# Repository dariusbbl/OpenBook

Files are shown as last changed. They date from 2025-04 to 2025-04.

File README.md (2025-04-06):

# OpenBook

# Block Diagram
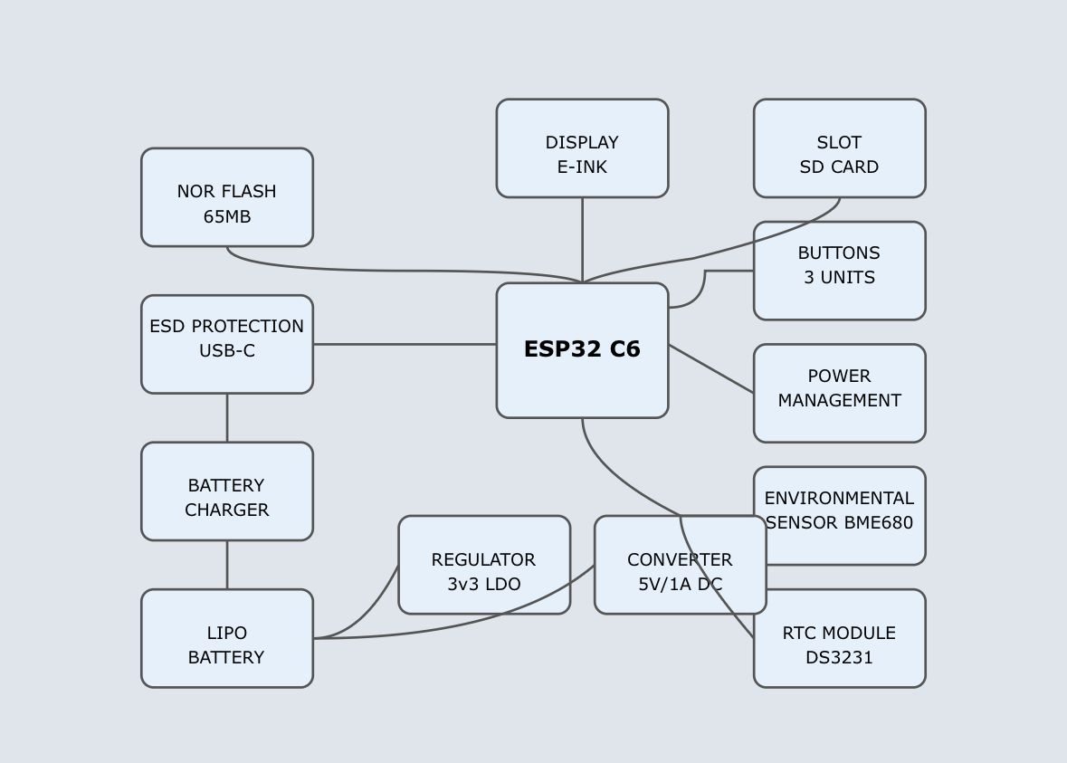
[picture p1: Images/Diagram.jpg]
Diagrama


# Hardware Components
#### Microcontroller – ESP32-C6
- **Core Architecture:** 32-bit RISC-V processor  
- **Wireless Support:** Integrated Wi-Fi 6 and Bluetooth Low Energy 5.0  
- **I/O Capabilities:** Supports multiple digital interfaces – SPI, I²C, UART, PWM, and general-purpose IO  
- **Power Features:** Low-energy design with deep sleep functionality for battery-powered applications

#### Real-Time Clock – DS3231SN
- **Accuracy:** ±2 ppm  
- **Communication:** I²C (`SDA`, `SCL`)  
- **Backup Power:** Supercapacitor-based retention

#### E-Paper Display
- **Connection Method:** 20-pin dedicated header  
- **Communication Protocol:** SPI + GPIO  
- **Key Signals:** `EPD_CS`, `EPD_DC`, `EPD_RST`, `EPD_BUSY`, etc.  
- **Advantages:** Zero power draw when idle, high readability in sunlight

#### MicroSD Card Slot
- **Interface:** SPI (connected to IO4 through IO9)  
- **Purpose:** Storing eBooks, setting and user configuration data  

#### Environmental Sensor – BME688
- **Measurements:** Temperature, Humidity, Pressure and VOCs  
- **Interface:** I²C  
- **Pins:** `SDA` – IO1, `SCL` – IO2  
- **Power Supply:** 3.3V  
- **Default Address:** `0x76` 

#### Environmental Sensor – BME688 Battery Fuel Gauge - MAX17048
- **Role:** Estimates remaining charge in LiPo(Lithium Polymer) battery
- **Protocol:** I²C (shared on IO1, IO2)  

#### Environmental Sensor – BME688 I²C Expansion – Qwiic / Stemma QT
- **Connector:** 4-pin (3V3, GND, SDA, SCL)  
- **Protocol:** I²C (`IO1`, `IO2`)  
- **Compatibility:** Plug-and-play with Adafruit / SparkFun modules  

#### Environmental Sensor – BME688 Voltage Supervisor – BD52xx
- **Purpose:** Monitors voltage levels, triggers safe reset  
- **Control Pin:** IO0

#### MCP73831 – Charging Controller
- **Function:** LiPo charging via USB (3.7V)  
- **Charging Current:** ~500 mA  
- **Indicator:** Status LED  

# BOM (Bill Of Materials)

| Componenta | Link | Datasheet |
|---|---|---|
| BUTTON | [Model](https://industry.panasonic.com/global/en/products/control/switch/light-touch/number/evqpuj02k) | [Datasheet](https://www.lcsc.com/datasheet/lcsc_datasheet_2201121800_PANASONIC-EVQPUJ02K_C2936858.pdf) |
| CAPACITOR | [Model](https://componentsearchengine.com/part-view/R0402%201%25%20100%20K%20(RC0402FR-07100KL)/YAGEO) | [Datasheet](//efaidnbmnnnibpcajpcglclefindmkaj/https://www.resistor.com/assets/pdf/0402tstd.pdf) |
| CPH3225A | [Model](https://www.snapeda.com/parts/CPH3225A/Seiko+Instruments/view-part/?ref=eda) | [Datasheet](https://octopart.com/datasheet/cph3225a-seiko-25340571) |
| EVQPUJ02K | [Model](https://industry.panasonic.com/global/en/products/control/switch/light-touch/number/evqpuj02k) | [Datasheet](https://www.lcsc.com/datasheet/lcsc_datasheet_2201121800_PANASONIC-EVQPUJ02K_C2936858.pdf) |
| KP-1608SURCK | [Model](https://www.snapeda.com/parts/KP-1608SURCK/Kingbright/view-part/?ref=search&t=LED%200603) | [Datasheet](//efaidnbmnnnibpcajpcglclefindmkaj/https://media.elv.com/file/107153_led_surck1608_data.pdf) |
| USBLC6-2SC6Y | [Model](https://www.snapeda.com/parts/USBLC6-2SC6Y/STMicroelectronics/view-part/?ref=eda) | [Datasheet](https://www.digikey.com/en/htmldatasheets/production/1375342/0/0/1/usblc6-2sc6y) |
| SD0805S020S1R0 | [Model](https://ro.mouser.com/ProductDetail/KYOCERA-AVX/SD0805S020S1R0?qs=jCA%252BPfw4LHbpkAoSnwrdjw%3D%3D) | [Datasheet](https://www.alldatasheet.com/view.jsp?Searchword=SD0805S&sField=2) |
| PGB1010603MR | [Model](https://www.snapeda.com/parts/PGB1010603MR/Littelfuse/view-part/?ref=eda) | [Datasheet](https://www.alldatasheet.com/view.jsp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) |
| BD5229G-TR  | [Model](https://componentsearchengine.com/part-view/BD5229G-TR/ROHM%20Semiconductor) | [Datasheet](https://www.lcsc.com/datasheet/lcsc_datasheet_2201131330_ROHM-Semicon-BD5229G-TR_C962636.pdf) |
| XC6220A331MR-G | [Model](https://componentsearchengine.com/part-view/XC6220A331MR-G/Torex) | [Datasheet](https://www.alldatasheet.com/view.jsp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) |
| XC6220A331MR-G | [Model](https://componentsearchengine.com/part-view/XC6220A331MR-G/Torex) | [Datasheet](https://www.alldatasheet.com/view.jsp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) |
| USB4110-GF-A  | [Model](https://componentsearchengine.com/part-view/USB4110-GF-A/GCT%20(GLOBAL%20CONNECTOR%20TECHNOLOGY)) | [Datasheet](//efaidnbmnnnibpcajpcglclefindmkaj/https://gct.co/files/drawings/usb4110.pdf) |
| Adafruit | [Model](https://eu.mouser.com/ProductDetail/Adafruit/4208?qs=PzGy0jfpSMtbScLbr0L5dw%3D%3D) | [Datasheet](https://www.arrow.com/en/manufacturers/adafruit-industries/datasheets) |
| Bobina | [Model](https://store.comet.srl.ro/Catalogue/Product/43497/) | [Datasheet](https://www.scribd.com/document/814581278/Datasheet-Bobina) |
| PFMF | [Model](https://www.mouser.co.uk/ProductDetail/EPCOS-TDK/B72520T0350K062?qs=dEfas%2FXlABIszF52uu7vrg%3D%3D) | [Datasheet](https://ro.mouser.com/c/ds/circuit-protection/thermistors/resettable-fuses-pptc/?m=Schurter&series=PFMF) |
| DMG2305UX-7 | [Model](https://componentsearchengine.com/part-view/DMG2305UX-7/Diodes%20Incorporated) | [Datasheet](//efaidnbmnnnibpcajpcglclefindmkaj/https://www.mouser.com/datasheet/2/115/DMG2305UX-266242.pdf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) |
| Si1308EDL-T1-GE3 | [Model](https://componentsearchengine.com/part-view/SI1308EDL-T1-GE3/Vishay) | [Datasheet](https://www.alldatasheet.com/view.jsp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) |
| R0402 | [Model](https://componentsearchengine.com/part-view/R0402%201%25%20100%20K%20(RC0402FR-07100KL)/YAGEO) | [Datasheet](//efaidnbmnnnibpcajpcglclefindmkaj/https://www.resistor.com/assets/pdf/0402tstd.pdf) |
| BME680 | [Model](https://www.snapeda.com/parts/BME680/Bosch/view-part/?welcome=home) | [Datasheet](//efaidnbmnnnibpcajpcglclefindmkaj/https://www.bosch-sensortec.com/media/boschsensortec/downloads/datasheets/bst-bme680-ds001.pdf) |
| SMD Solder | [Model](https://grabcad.com/library/solder-jumpers-1) | [Datasheet]() |
| W25Q512JVEIQ | [Model](https://www.snapeda.com/parts/ESP32-C6-WROOM-1-N8/Espressif+Systems/view-part/?ref=eda) | [Datasheet](//efaidnbmnnnibpcajpcglclefindmkaj/https://www.mouser.com/datasheet/2/949/W25Q512JV_SPI_RevB_06252019_KMS-2487502.pdf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) |
| ESP32-C6-WROOM-1-N8 | [Model](https://www.snapeda.com/parts/ESP32-C6-WROOM-1-N8/Espressif+Systems/view-part/?ref=eda) | [Datasheet](//efaidnbmnnnibpcajpcglclefindmkaj/https://www.mouser.com/catalog/specsheets/Espressif_ESP32_C6_WROOM_1%20_Datasheet_V0.1_PRELIMINARY_en.pdf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) |
| DS3231SN# | [Model](https://www.snapeda.com/parts/DS3231SN%23/Analog+Devices/view-part/?ref=eda) | [Datasheet](https://www.alldatasheet.com/view.jsp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) |
| MAX17048G+T10 | [Model](https://www.snapeda.com/parts/MAX17048G+T10/Analog+Devices/view-part/?ref=eda) | [Datasheet](https://www.alldatasheet.com/view.jsp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) |
| MCP73831T-5ACI/OT | [Model](https://www.mouser.co.uk/ProductDetail/Microchip-Technology/MCP73831T-5ACI-OT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) | [Datasheet](//efaidnbmnnnibpcajpcglclefindmkaj/https://ww1.microchip.com/downloads/en/DeviceDoc/MCP73831-Family-Data-Sheet-DS20001984H.pdf) |

### ESP32-C6 Hardware Connections Overview  

| **Peripheral** | **Connected Pin(s)** | **Protocol** | **Functionality Description** |
|---|---|---|---|
| **E-Paper Display** | IO7 (MOSI), IO6 (SCK), IO10 (CS), IO5 (DC), IO23 (RST), IO3 (BUSY) | SPI | Sends visual data and manages display operations. |
| **MicroSD Card Module** | IO7 (MOSI), IO6 (SCK), IO4 (SS_SD), IO2 (MISO) | SPI | Enables saving and reading of e-book files. |
| **BME688 Environmental Sensor** | IO21 (SDA), IO22 (SCL) | I2C | Measures environmental factors like temperature, humidity, pressure, and gas levels. |
| **DS3231 RTC Module** | IO21 (SDA), IO22 (SCL), IO18 (RST), IO1 (32KHz), IO0 (INT_RTC) | I2C | Maintains accurate timekeeping even when the main system is off. |
| **External NOR Flash** | IO11 (CS), IO6 (SCK), IO2 (MISO), IO7 (MOSI) | SPI | Offers extra non-volatile memory for storing application-specific data. |
| **Battery Status Monitor**  | IO21 (SDA), IO22 (SCL) | I2C | Monitors power level and battery condition. |
| **USB-C Interface** | GPIOs via regulated voltage lines | USB | Supplies power and facilitates programming access. |
| **User Input Buttons** | IO9 (BOOT), IO15 (CHANGE), EN (RESET) | GPIO | Detects user interaction through physical button presses. |

# Decision & Modifications
- To address the design checker errors, I adjusted the dimensions of several components.
- The main components were positioned exactly according to the provided specifications to ensure a perfect match between the PCB dimensions and the case. Component placement was carefully planned to allow for efficient routing. The battery was placed in the remaining free space within the case.
- A ground plane was created on both the top and bottom layers to improve signal integrity and reduce noise.
- Routing was performed on both the top and bottom layers. Power traces were placed exclusively on the top layer to avoid the use of vias.
- Diodes (SMD-Hole): The initial footprint included through-hole pads that were too narrow, potentially leading to soldering difficulties and poor connectivity. To address this, the pad dimensions were modified to 35 mil × 190 mil, improving both manufacturability and the reliability of the electrical contact.
- U4 – MAX17048G+T10: The VBAT power trace was routed with a width of 0.3 mm due to design constraints. However, the original footprint featured pin widths of just 0.27 mm, which caused mismatches and disrupted routing symmetry. The pad widths were therefore increased to match the trace width, ensuring consistent routing and improved layout balance.

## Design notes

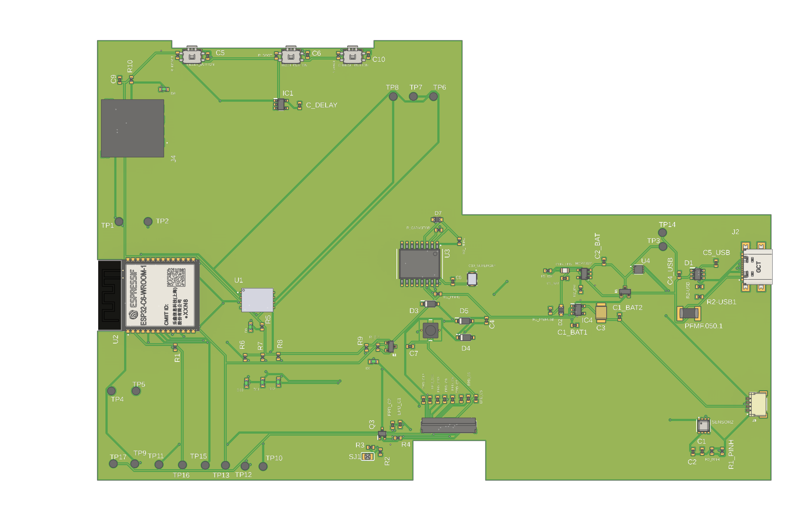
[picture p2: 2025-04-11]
Images/3D_updated.png

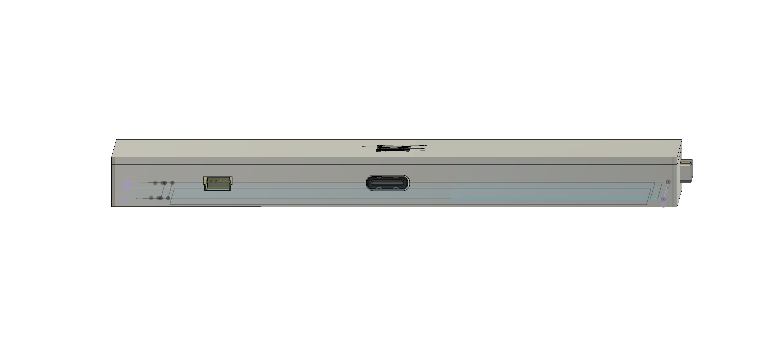
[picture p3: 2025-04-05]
Images/Ports.png

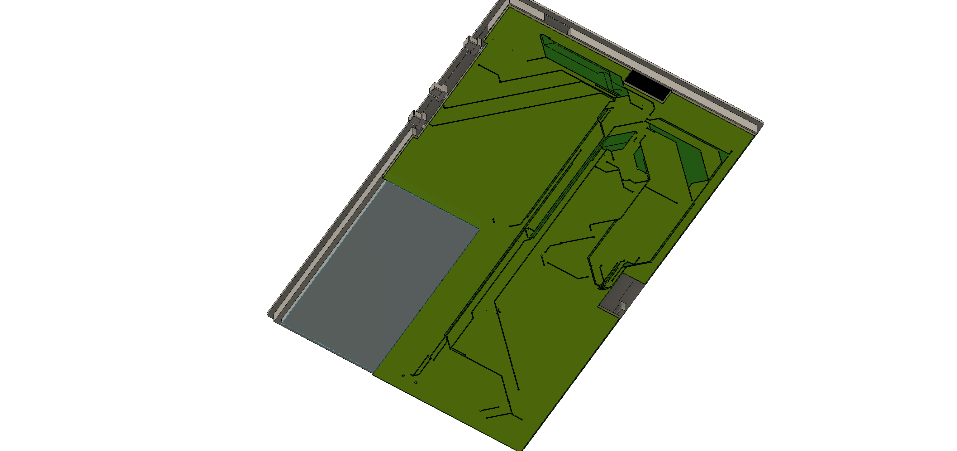
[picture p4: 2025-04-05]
Images/BoardBack.png

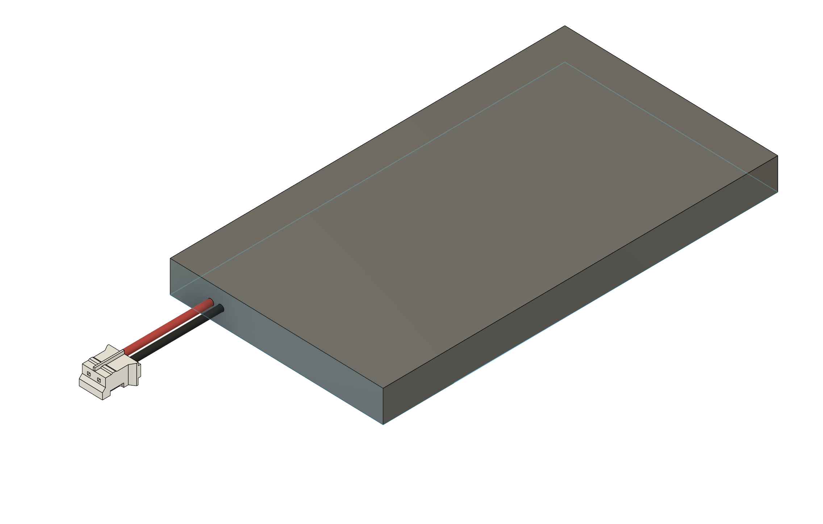
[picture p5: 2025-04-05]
Images/Battery.png

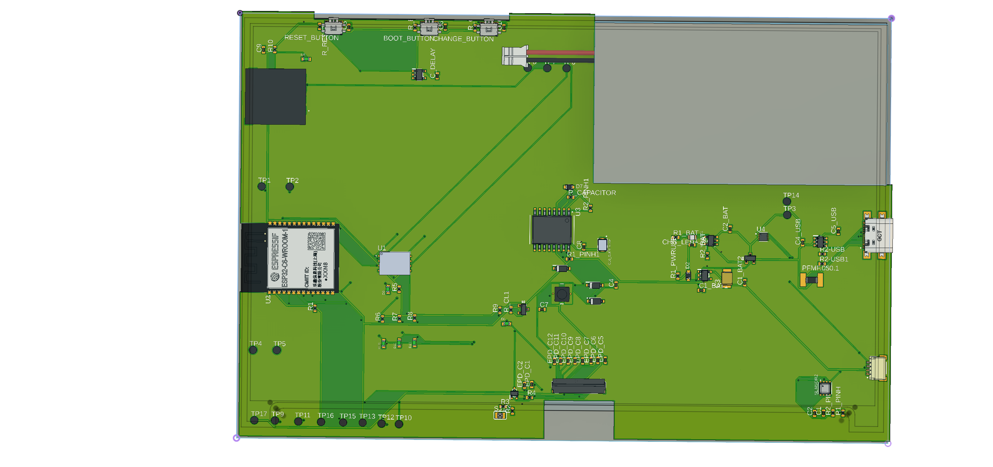
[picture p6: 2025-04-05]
Images/Board.png

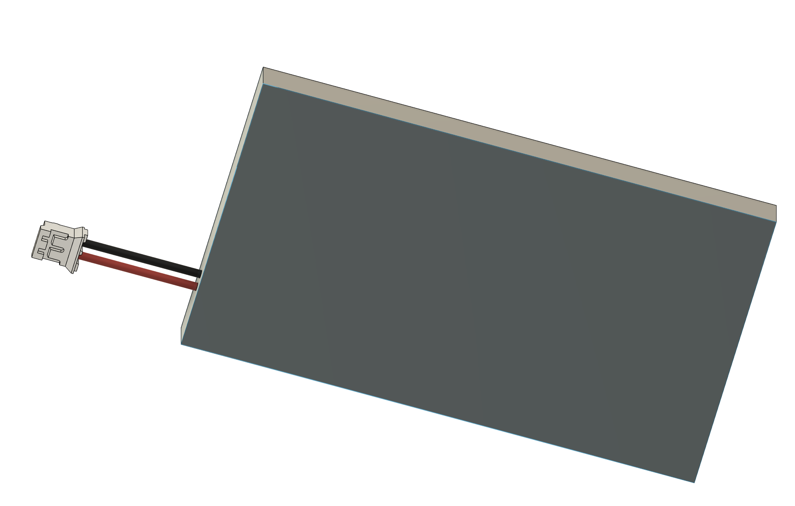
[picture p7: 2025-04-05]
Images/BatteryBack.png

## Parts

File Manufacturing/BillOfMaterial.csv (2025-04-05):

Qty | Value | Device | Package | Parts | Description | ARROW_PART_NUMBER | ARROW_PRICE-STOCK | AVAILABILITY | CENTROID_NOT_SPECIFIED | CHECK_PRICES | COPYRIGHT | DATASHEET | DESCRIPTION | DIGIKEY_DESCRIPTION | DIGIKEY_PART_NUMBER | HEIGHT | LEAD_FREE | MANUFACTURER_NAME | MANUFACTURER_PART_NUMBER | MF | MFR_NAME | MOUSER_PART_NUMBER | MOUSER_PRICE-STOCK | MOUSER_TESTING_PART_NUMBER | MOUSER_TESTING_PRICE-STOCK | MP | MPN | PACKAGE | POPULARITY | PREFIX | PRICE | PROD_ID | PURCHASE-URL | ROHS | SNAPEDA_LINK | SPICEMODEL | SPICEPREFIX | TEMPERATURE_RANGE_HIGH | TEMPERATURE_RANGE_LOW | TP_SIGNAL_NAME | VALUE
1 |  | ADAFRUIT_LEDCHIP-LED0603 | ADAFRUIT_CHIP-LED0603 | CHG_LED | LED
1 |  | SJ | SJ | SJ1 | SMD solder JUMPER |  |  |  |  |  |  |  |  |  |  |  |  |  |  |  |  |  |  |  |  |  |  |  | 3
1 | 0.1uF/50V | ESP32_WROVER_EAGLE-LTSPICE_CC0402 | ESP32_WROVER_EAGLE-LTSPICE_C0402 | EPD_C5 | CAPACITOR, European symbol |  |  |  |  |  |  |  |  |  |  |  |  |  |  |  |  |  |  |  |  |  |  |  |  |  |  |  |  |  |  | NONE | C
1 | 0.47 | ESP32_WROVER_EAGLE-LTSPICE_RR0402 | ESP32_WROVER_EAGLE-LTSPICE_R0402 | R3 | RESISTOR, European symbol |  |  |  |  |  |  |  |  |  |  |  |  |  |  |  |  |  |  |  |  |  |  |  |  |  |  |  |  |  |  | NONE | R
1 | 100K | ESP32_WROVER_EAGLE-LTSPICE_RR0402 | ESP32_WROVER_EAGLE-LTSPICE_R0402 | R1_PWRUSB | RESISTOR, European symbol |  |  |  |  |  |  |  |  |  |  |  |  |  |  |  |  |  |  |  |  |  |  |  |  |  |  |  |  |  |  | NONE | R
8 | 100nF | ESP32_WROVER_EAGLE-LTSPICE_CC0402 | ESP32_WROVER_EAGLE-LTSPICE_C0402 | C1, C2, C4_USB, C6, C8, C9, C10, C_DELAY | CAPACITOR, European symbol |  |  |  |  |  |  |  |  |  |  |  |  |  |  |  |  |  |  |  |  |  |  |  |  |  |  |  |  |  |  | NONE | C
1 | 100uF TANT | RCL_CPOL-EUCT3528 | RCL_CT3528 | C3 | POLARIZED CAPACITOR, European symbol |  |  |  |  |  |  |  |  |  |  |  |  |  |  |  |  |  |  |  |  |  |  |  | 0 |  |  |  |  |  |  |  | C
15 | 10K | ESP32_WROVER_EAGLE-LTSPICE_RR0402 | ESP32_WROVER_EAGLE-LTSPICE_R0402 | R1, R1_PINH, R1_PINH1, R2_PINH, R2_PINH1, R4, R5, R6, R7, R9, R10, R_BOOT, R_CHANGE, R_CL1, R_RESET | RESISTOR, European symbol |  |  |  |  |  |  |  |  |  |  |  |  |  |  |  |  |  |  |  |  |  |  |  |  |  |  |  |  |  |  | NONE | R
1 | 10k | ESP32_WROVER_EAGLE-LTSPICE_RR0402 | ESP32_WROVER_EAGLE-LTSPICE_R0402 | R8 | RESISTOR, European symbol |  |  |  |  |  |  |  |  |  |  |  |  |  |  |  |  |  |  |  |  |  |  |  |  |  |  |  |  |  |  | NONE | R
1 | 10uF | ESP32_WROVER_EAGLE-LTSPICE_CC0402 | ESP32_WROVER_EAGLE-LTSPICE_C0402 | C7 | CAPACITOR, European symbol |  |  |  |  |  |  |  |  |  |  |  |  |  |  |  |  |  |  |  |  |  |  |  |  |  |  |  |  |  |  | NONE | C
1 | 112A-TAAR-R03_ATTEND | 112A-TAAR-R03_ATTEND | 112ATAARR03ATTEND | J4 | Micro SD Card Socket, Push-Push Type, Top Mount, SMT, H=1.83mm, 10u |  |  |  |  |  |  |  | Micro SD Card Socket | Push-Push Type | Top Mount | SMT | H=1.83mm | 10u |  |  | 1.9mm |  | ATTEND | 112A-TAAR-R03 ATTEND
1 | 15 | ESP32_WROVER_EAGLE-LTSPICE_RR0402 | ESP32_WROVER_EAGLE-LTSPICE_R0402 | R_CAPACITOR | RESISTOR, European symbol |  |  |  |  |  |  |  |  |  |  |  |  |  |  |  |  |  |  |  |  |  |  |  |  |  |  |  |  |  |  | NONE | R
1 | 1uF | ESP32_WROVER_EAGLE-LTSPICE_CC0402 | ESP32_WROVER_EAGLE-LTSPICE_C0402 | C5 | CAPACITOR, European symbol |  |  |  |  |  |  |  |  |  |  |  |  |  |  |  |  |  |  |  |  |  |  |  |  |  |  |  |  |  |  | NONE | C
9 | 1uF/50V | ESP32_WROVER_EAGLE-LTSPICE_CC0402 | ESP32_WROVER_EAGLE-LTSPICE_C0402 | EPD_C1, EPD_C2, EPD_C6, EPD_C7, EPD_C8, EPD_C9, EPD_C10, EPD_C11, EPD_C12 | CAPACITOR, European symbol |  |  |  |  |  |  |  |  |  |  |  |  |  |  |  |  |  |  |  |  |  |  |  |  |  |  |  |  |  |  | NONE | C
1 | 2.2 | ESP32_WROVER_EAGLE-LTSPICE_RR0402 | ESP32_WROVER_EAGLE-LTSPICE_R0402 | R2 | RESISTOR, European symbol |  |  |  |  |  |  |  |  |  |  |  |  |  |  |  |  |  |  |  |  |  |  |  |  |  |  |  |  |  |  | NONE | R
1 | 200 | ESP32_WROVER_EAGLE-LTSPICE_RR0402 | ESP32_WROVER_EAGLE-LTSPICE_R0402 | R1_BAT | RESISTOR, European symbol |  |  |  |  |  |  |  |  |  |  |  |  |  |  |  |  |  |  |  |  |  |  |  |  |  |  |  |  |  |  | NONE | R
2 | 20V/4.2A/52mO/1.4W | ESP32_WROVER_SPARKFUN-DISCRETESEMI_MOSFET_PCH-DMG2305UX-7 | ESP32_WROVER_SPARKFUN-DISCRETESEMI_SOT23-3 | Q1, Q2 | P-channel MOSFETs |  |  |  |  |  |  |  |  |  |  |  |  |  |  |  |  |  |  |  |  |  |  |  |  |  |  | TRAN-14388 |  |  |  |  |  |  |  |  | 20V/4.2A/52mO/1.4W
1 | 2K | ESP32_WROVER_EAGLE-LTSPICE_RR0402 | ESP32_WROVER_EAGLE-LTSPICE_R0402 | R2_BAT | RESISTOR, European symbol |  |  |  |  |  |  |  |  |  |  |  |  |  |  |  |  |  |  |  |  |  |  |  |  |  |  |  |  |  |  | NONE | R
5 | 4.7uF | ESP32_WROVER_EAGLE-LTSPICE_CC0402 | ESP32_WROVER_EAGLE-LTSPICE_C0402 | C1_BAT, C1_BAT1, C1_BAT2, C2_BAT, C5_USB | CAPACITOR, European symbol |  |  |  |  |  |  |  |  |  |  |  |  |  |  |  |  |  |  |  |  |  |  |  |  |  |  |  |  |  |  | NONE | C
1 | 4.7uF/25V | ESP32_WROVER_EAGLE-LTSPICE_CC0402 | ESP32_WROVER_EAGLE-LTSPICE_C0402 | C4 | CAPACITOR, European symbol |  |  |  |  |  |  |  |  |  |  |  |  |  |  |  |  |  |  |  |  |  |  |  |  |  |  |  |  |  |  | NONE | C
2 | 5k1 | ESP32_WROVER_EAGLE-LTSPICE_RR0402 | ESP32_WROVER_EAGLE-LTSPICE_R0402 | R2-USB, R2-USB1 | RESISTOR, European symbol |  |  |  |  |  |  |  |  |  |  |  |  |  |  |  |  |  |  |  |  |  |  |  |  |  |  |  |  |  |  | NONE | R
1 | 744043680IND_4828-WE-TPC_WRE | 744043680IND_4828-WE-TPC_WRE | IND_4828-WE-TPC_WRE | L1 |  |  |  |  |  |  | Copyright (C) 2024 Ultra Librarian. All rights reserved. |  |  |  |  |  |  |  | 744043680 |  | Wurth Electronics
1 | BD5229G-TR | BD5229G-TR | SOT95P280X125-5N | IC1 | Voltage Detector with Adjustable Delay Time: CMOS processes are utilized to develop high precision, low current consumption CMOS reset ICs that allow arbitrary setting of the delay time. The extensive lineup includes both Nch Open Drain and CMOS output types in a wide range of detection voltages (from 2.3V to 6.0V, in 0.1V steps), enabling selection of the ideal solution based on customer requirements. In addition, the entire series is of course both lead-free and RoHS-compliant. |  |  |  |  |  |  |  | Voltage Detector with Adjustable Delay Time: CMOS processes are utilized to develop high precision | low current consumption CMOS reset ICs that allow arbitrary setting of the delay time. The extensive lineup includes both Nch Open Drain and CMOS output types in a wide range of detection voltages (from 2.3V to 6.0V | in 0.1V steps) | enabling selection of the ideal solution based on customer requirements. In addition | the entire series is of course both lead-free and RoHS-compliant. |  |  | 1.25mm |  | ROHM Semiconductor | BD5229G-TR |  |  | 755-BD5229G-TR | https://www.mouser.co.uk/ProductDetail/ROHM-Semiconductor/BD5229G-TR?qs=4kLU8WoGk0vvnhrrYwdszw%3D%3D
3 | BUTTON_CUSYOMV1 | BUTTON_CUSYOMV1 | MYBUTTON | BOOT_BUTTON, CHANGE_BUTTON, RESET_BUTTON
1 | CPH3225A | CPH3225A | CAPCP3225X100N | C10_SUPERCAP | Cap 0.011F 3.3V 1210 Flat Check availability |  |  | Not in stock |  | https://www.snapeda.com/parts/CPH3225A/Seiko+Instruments/view-part/?ref=eda |  |  | 11 mF (EDLC) Supercapacitor 3.3 V 1210 (3225 Metric) - - |  |  |  |  |  |  | Seiko Instruments |  |  |  |  |  | CPH3225A |  | 1210 Seiko |  |  | None |  | https://www.snapeda.com/api/url_track_click_mouser/?unipart_id=562593&manufacturer=Seiko Instruments&part_name=CPH3225A&search_term=None |  | https://www.snapeda.com/parts/CPH3225A/Seiko+Instruments/view-part/?ref=snap
1 | DS3231SN# | DS3231SN# | SOIC127P1032X265-16N | U3 | Real Time Clock Serial 16-Pin SOIC W T/R Check availability |  |  | In Stock |  | https://www.snapeda.com/parts/DS3231SN%23/Analog+Devices/view-part/?ref=eda |  |  | Extremely Accurate I²C-Integrated RTC/TCXO/Crystal |  |  |  |  |  |  | Analog Devices |  |  |  |  |  | DS3231SN# |  | SOIC-16 Maxim |  |  | None |  | https://www.snapeda.com/api/url_track_click_mouser/?unipart_id=99048&manufacturer=Analog Devices&part_name=DS3231SN#&search_term=None |  | https://www.snapeda.com/parts/DS3231SN%23/Analog+Devices/view-part/?ref=snap
1 | ESP32-C6-WROOM-1-N8 | ESP32-C6-WROOM-1-N8 | XCVR_ESP32-C6-WROOM-1-N8 | U2 | Check availability |  |  | In Stock |  | https://www.snapeda.com/parts/ESP32-C6-WROOM-1-N8/Espressif+Systems/view-part/?ref=eda |  |  | Multiprotocol Modules ESP32-C6 module | Wi-Fi 6 in 2.4 GHz band | Bluetooth 5 | Zigbee 3.0 and Thread. ESP34-WROOM Compatible - ENGINEERING SAMPLE |  |  |  |  |  |  | Espressif Systems |  |  |  |  |  | ESP32-C6-WROOM-1-N8 |  | None |  |  | None |  |  |  | https://www.snapeda.com/parts/ESP32-C6-WROOM-1-N8/Espressif+Systems/view-part/?ref=snap
1 | ESP32C6_VARISTORCN1812 | ESP32C6_VARISTORCN1812 | ESP32C6_VARISTOR_CT/CN1812 | PFMF.050.1 | VARISTOR |  |  |  |  |  |  |  |  |  |  |  |  |  |  |  |  |  |  |  |  |  |  |  | 0
2 | ESP32_WROVER_AVX---SD0805S020S1R0_AVX_SD0805S020S1R0_0_0AVX_SD0805S020S1R0_0_0 | ESP32_WROVER_AVX---SD0805S020S1R0_AVX_SD0805S020S1R0_0_0AVX_SD0805S020S1R0_0_0 | ESP32_WROVER_AVX---SD0805S020S1R0_AVX_SD0805S020S1R0_0 | D2, D7 | Schottky Barrier Rectifier Diode |  |  |  | No |  |  | http://datasheets.avx.com/schottky.pdf |  | DIODE SCHOTTKY 20V 1A 0805 | 478-7800-1-ND |  | yes |  |  | AVX |  | 581-SD0805S020S1R0 |  |  |  |  |  | 0805 (2012 metric) |  | D |  |  |  | yes |  |  |  | +125°C | -55°C
1 | ESP32_WROVER_BME680_BME6801 | ESP32_WROVER_BME680_BME6801 | ESP32_WROVER_BME680_PSON80P300X300X100-8N | SENSOR2 | Integrated Environmental Unit
1 | ESP32_WROVER_SPARKFUN-IC-POWER_MCP73831 | ESP32_WROVER_SPARKFUN-IC-POWER_MCP73831 | ESP32_WROVER_SPARKFUN-IC-POWER_SOT23-5 | MCP73831 | MCP73831T Li-Ion, Li-Pol Controller |  |  |  |  |  |  |  |  |  |  |  |  |  |  |  |  |  |  |  |  |  |  |  |  |  |  | IC-09995
1 | FH34SRJ-24S-0.5SH_99_ | FH34SRJ-24S-0.5SH_99_ | FH34SRJ24S05SH99 | J1 | (0.50mm) Surface Mount, Right Angle |  |  |  |  |  |  |  | 24 Position FFC | FPC Connector Contacts | (0.50mm) Surface Mount | Right Angle |  |  | 1.1mm |  | Hirose | FH34SRJ-24S-0.5SH(99) |  |  | 798-FH34SRJ24S05SH99 | https://www.mouser.co.uk/ProductDetail/Hirose-Connector/FH34SRJ-24S-0.5SH99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
1 | MAX17048G+T10 | MAX17048G+T10 | SON50P200X200X80-9N | U4 | Check availability |  |  | In Stock |  | https://www.snapeda.com/parts/MAX17048G+T10/Analog+Devices/view-part/?ref=eda |  |  | 3µA 1-Cell/2-Cell Fuel Gauge with ModelGauge |  |  |  |  |  |  | Analog Devices |  |  |  |  |  | MAX17048G+T10 |  | TDFN-8 Maxim |  |  | None |  | https://www.snapeda.com/api/url_track_click_mouser/?unipart_id=329239&manufacturer=Analog Devices&part_name=MAX17048G+T10&search_term=None |  | https://www.snapeda.com/parts/MAX17048G+T10/Analog+Devices/view-part/?ref=snap
3 | MBR0530 | MBR0530 | SOD3716X135N | D3, D4, D5 | ON SEMICONDUCTOR - MBR0530 - DIODE, SCHOTTKY, 0.5A, 30V, SOD-123 |  |  | In Stock |  | https://www.snapeda.com/parts/MBR0530/Onsemi/view-part/?ref=eda |  |  | Diode Schottky 30 V 500mA Surface Mount SOD-123 |  |  |  |  |  |  | ON Semiconductor |  |  |  |  |  | MBR0530 |  | SOD-123-2 ON Semiconductor |  |  | None |  | https://www.snapeda.com/api/url_track_click_mouser/?unipart_id=179458&manufacturer=ON Semiconductor&part_name=MBR0530&search_term=None |  | https://www.snapeda.com/parts/MBR0530/Onsemi/view-part/?ref=snap
6 | PGB1010603MR | PGB1010603MR | DIOC1608X36N | D6, D8, D9, D10, D11, D12 | Check availability |  |  | In Stock |  | https://www.snapeda.com/parts/PGB1010603MR/Littelfuse/view-part/?ref=eda |  |  | 150V (Typ) Clamp - Ipp Tvs Diode Surface Mount 0603 (1608 Metric) |  |  |  |  |  |  | Littelfuse Inc. |  |  |  |  |  | PGB1010603MR |  | 0603 Littelfuse Inc. |  |  | None |  | https://www.snapeda.com/api/url_track_click_mouser/?unipart_id=5659453&manufacturer=Littelfuse Inc.&part_name=PGB1010603MR&search_term=None |  | https://www.snapeda.com/parts/PGB1010603MR/Littelfuse/view-part/?ref=snap
1 | QWIIC_RIGHT_ANGLE | QWIIC_CONNECTORJS-1MM | JST04_1MM_RA | J3 | SparkFun I2C Standard Qwiic Connector |  |  |  |  |  |  |  |  |  |  |  |  |  |  |  |  |  |  |  |  |  |  |  |  |  |  | CONN-13694 |  |  |  |  |  |  |  |  | QWIIC_RIGHT_ANGLE
1 | SAMACSYS_PARTS_USB4110-GF-A | SAMACSYS_PARTS_USB4110-GF-A | SAMACSYS_PARTS_USB4110GFA | J2 | CONN USB 2.0 TYPE-C R/A SMT |  |  |  |  |  |  |  | CONN USB 2.0 TYPE-C R/A SMT |  |  | 3.26mm |  | GCT (GLOBAL CONNECTOR TECHNOLOGY) | USB4110-GF-A |  |  | 640-USB4110-GF-A | https://www.mouser.co.uk/ProductDetail/GCT/USB4110-GF-A?qs=KUoIvG%2F9IlYiZvIXQjyJeA%3D%3D
1 | SI1308EDL-T1-GE3 | SI1308EDL-T1-GE3 | SOT65P210X110-3N | Q3 | MOSFET N-Ch 30V 1.5A TrenchFET SC70 Vishay Si1308EDL-T1-GE3 N-channel MOSFET Transistor, 1.5 A, 30 V, 3-Pin SC-70 |  |  | In Stock |  | https://www.snapeda.com/parts/SI1308EDL-T1-GE3/Vishay+Siliconix/view-part/?ref=eda |  |  | Si1308EDL-T1-GE3 N-channel MOSFET Transistor | 1.5 A | 30 V | 3-Pin SC-70 | Siliconix / Vishay SI1308EDL-T1-GE3 |  |  |  |  |  |  | Vishay Siliconix |  |  |  |  |  | SI1308EDL-T1-GE3 |  | SOT-323 Vishay Semiconductor |  |  | None |  | https://www.snapeda.com/api/url_track_click_mouser/?unipart_id=274603&manufacturer=Vishay Siliconix&part_name=SI1308EDL-T1-GE3&search_term=None |  | https://www.snapeda.com/parts/SI1308EDL-T1-GE3/Vishay+Siliconix/view-part/?ref=snap
17 | TPTP20R | TPTP20R | TP20R | TP1, TP2, TP3, TP4, TP5, TP6, TP7, TP8, TP9, TP10, TP11, TP12, TP13, TP14, TP15, TP16, TP17 | Test pad |  |  |  |  |  |  |  |  |  |  |  |  |  |  |  |  |  |  |  |  |  |  |  | 2
1 | USBLC6-2SC6Y | USBLC6-2SC6Y | SOT95P280X145-6N | D1 | Low Cap. ESD Protection Auto SOT-23-6 STMicroelectronics USBLC6-2SC6Y, Dual Uni-Directional TVS Diode Array, 6-Pin SOT-23 |  |  | In Stock |  | https://www.snapeda.com/parts/USBLC6-2SC6Y/STMicroelectronics/view-part/?ref=eda |  |  | 17V Clamp 5A (8/20µs) Ipp Tvs Diode Surface Mount SOT-23-6 |  |  |  |  |  |  | STMicroelectronics |  |  |  |  |  | USBLC6-2SC6Y |  | SOT-23-6 STMicroelectronics |  |  | None |  |  |  | https://www.snapeda.com/parts/USBLC6-2SC6Y/STMicroelectronics/view-part/?ref=snap
1 | W25Q512JVEIQ | W25Q512JVEIQ | SON127P600X800X80-9N | U1 | Check availability |  |  | In Stock |  | https://www.snapeda.com/parts/W25Q512JVEIQ/Winbond+Electronics/view-part/?ref=eda |  |  | FLASH - NOR Memory IC 512Mb (64M x 8) SPI - Quad I/O 133 MHz 8-WSON (8x6) |  |  |  |  |  |  | Winbond Electronics |  |  |  |  |  | W25Q512JVEIQ |  | Package |  |  | None |  |  |  | https://www.snapeda.com/parts/W25Q512JVEIQ/Winbond+Electronics/view-part/?ref=snap
1 | XC6220A331MR-G | XC6220A331MR-G | SOT95P280X120-5N | IC4 | LDO Voltage Regulators |  |  |  |  |  |  |  | LDO Voltage Regulators |  |  | 1.2mm |  | Torex | XC6220A331MR-G |  |  | 865-XC6220A331MR-G | https://www.mouser.co.uk/ProductDetail/Torex-Semiconductor/XC6220A331MR-G?qs=AsjdqWjXhJ8ZSWznL1J0gg%3D%3D

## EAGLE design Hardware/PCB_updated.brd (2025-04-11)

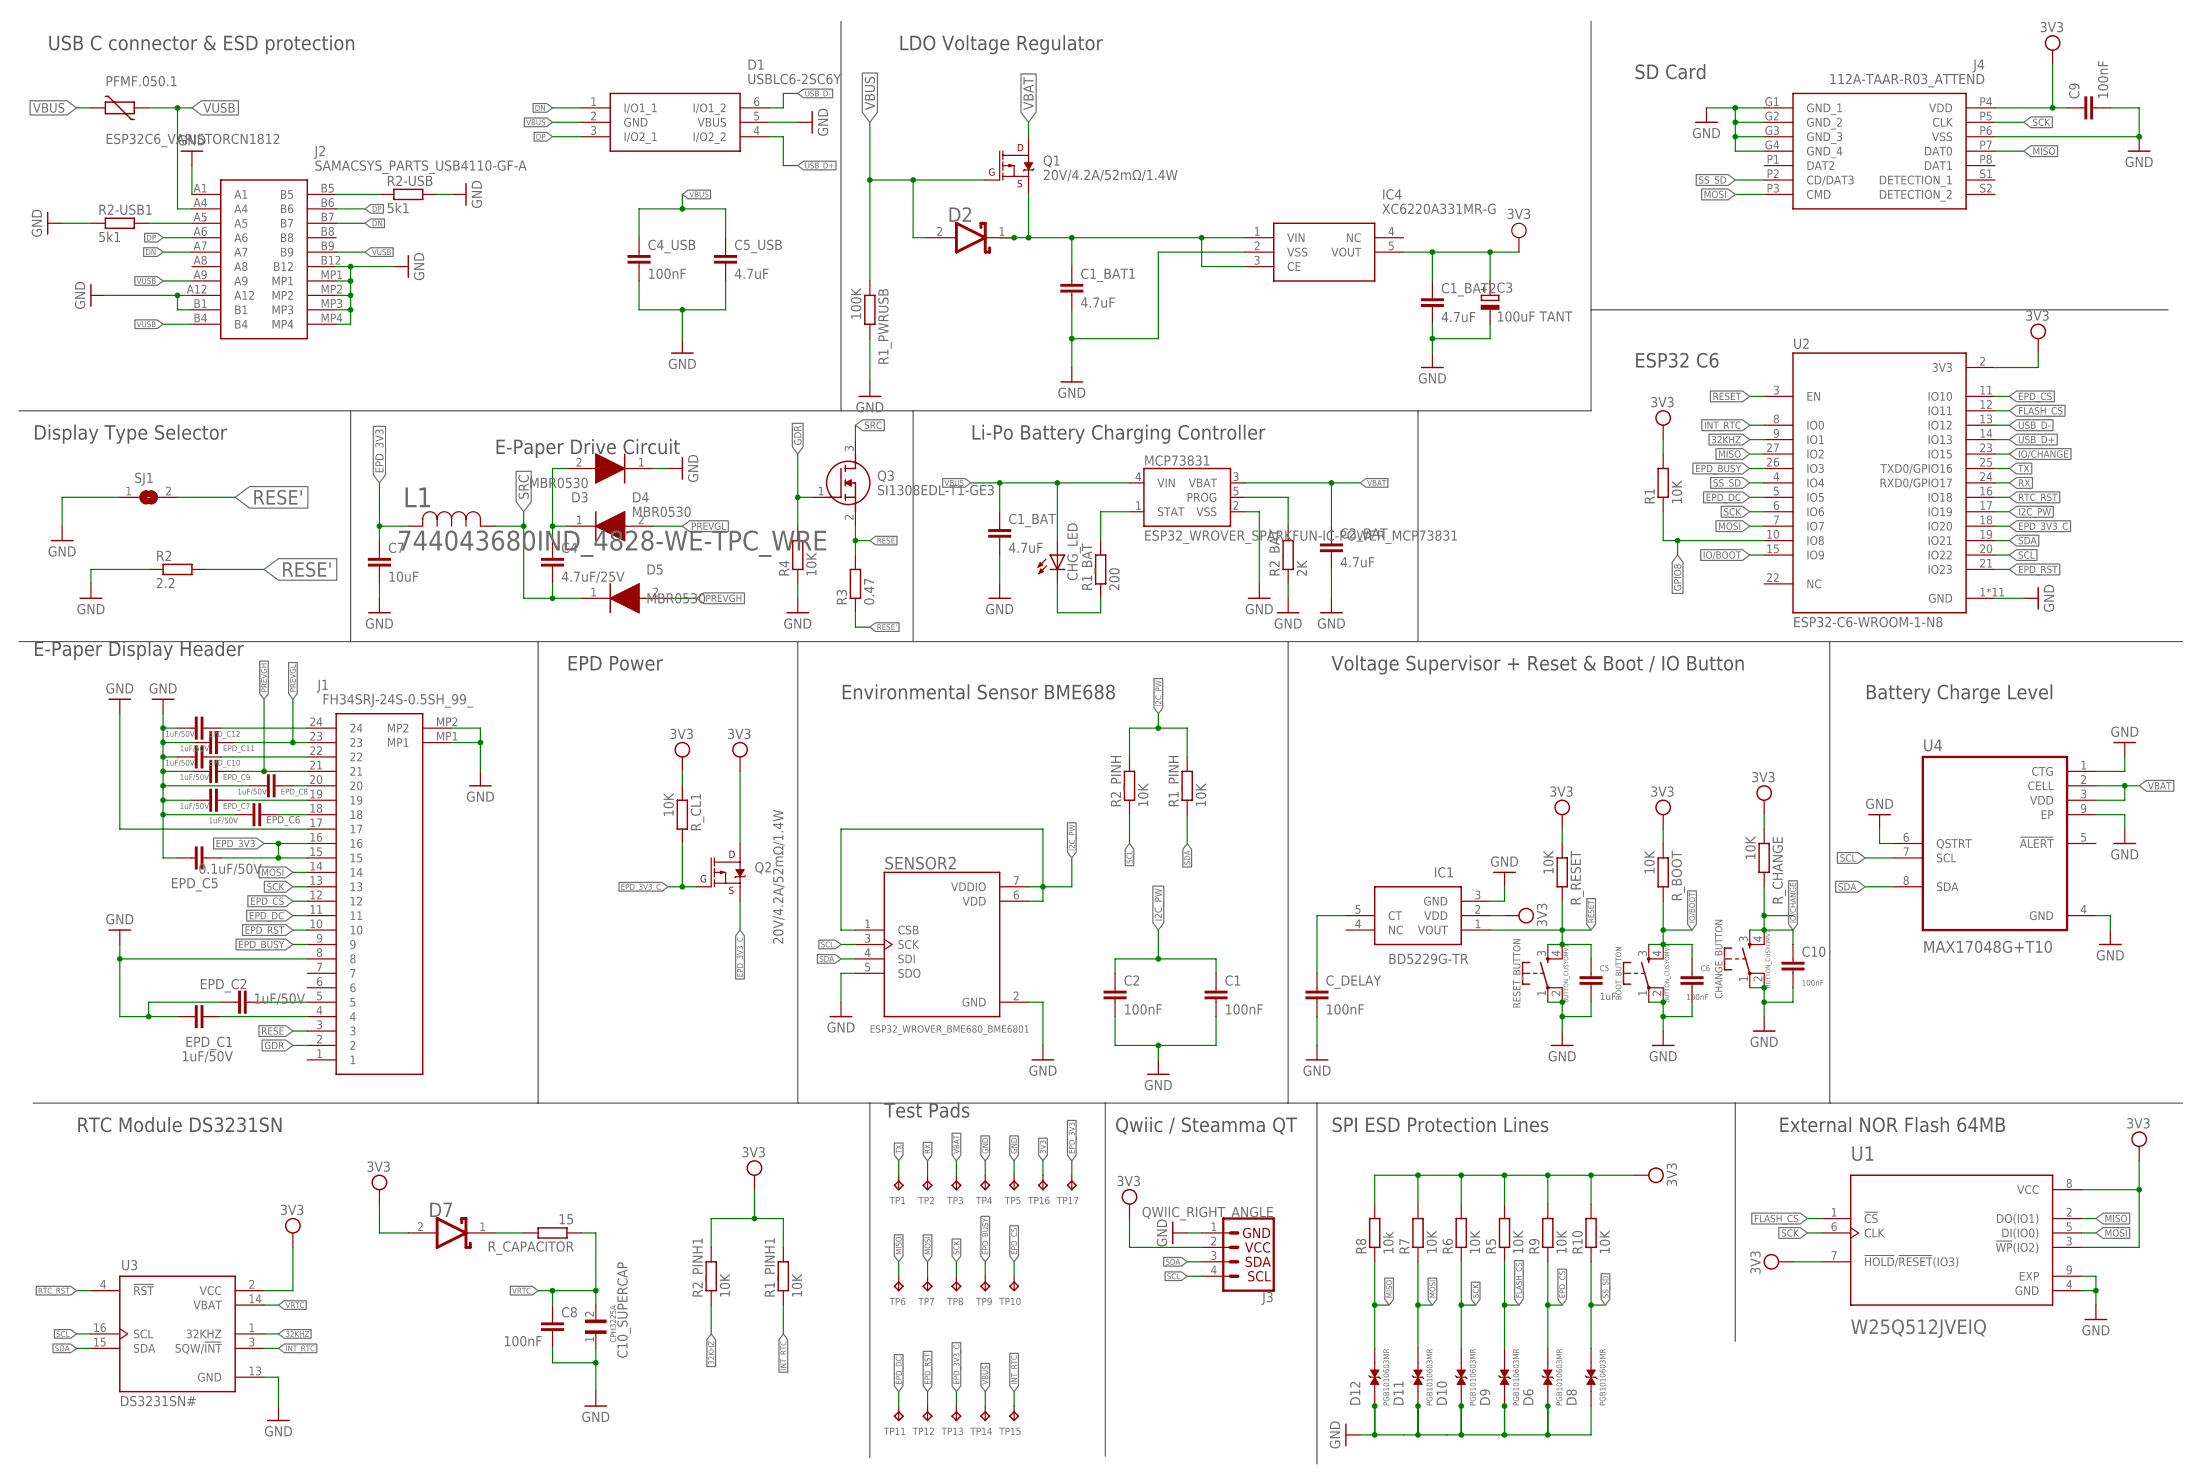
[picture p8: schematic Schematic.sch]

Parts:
BOOT_BUTTON: BUTTON_CUSYOMV1; MYBUTTON
C1, C2, C4_USB, C6, C8, C9, C10: 100nF; ESP32_WROVER_EAGLE-LTSPICE_C0402
C1_BAT, C1_BAT1, C1_BAT2, C2_BAT, C5_USB: 4.7uF; ESP32_WROVER_EAGLE-LTSPICE_C0402
C3: 100uF TANT; RCL_CT3528
C4: 4.7uF/25V; ESP32_WROVER_EAGLE-LTSPICE_C0402
C5: 1uF; ESP32_WROVER_EAGLE-LTSPICE_C0402
C7: 10uF; ESP32_WROVER_EAGLE-LTSPICE_C0402
C10_SUPERCAP: CPH3225A; CAPCP3225X100N
CHANGE_BUTTON: BUTTON_CUSYOMV1; MYBUTTON
CHG_LED: ADAFRUIT_LEDCHIP-LED0603; ADAFRUIT_CHIP-LED0603
C_DELAY: 100nF; ESP32_WROVER_EAGLE-LTSPICE_C0402
D1: USBLC6-2SC6Y; SOT95P280X145-6N
D2, D7: ESP32_WROVER_AVX---SD0805S020S1R0_AVX_SD0805S020S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; ESP32_WROVER_AVX---SD0805S020S1R0_AVX_SD0805S020S1R0_0
D3, D4, D5: MBR0530; SOD3716X135N
D6, D8, D9, D10, D11, D12: PGB1010603MR; DIOC1608X36N
EPD_C1, EPD_C2, EPD_C6, EPD_C7, EPD_C8, EPD_C9, EPD_C10, EPD_C11, EPD_C12: 1uF/50V; ESP32_WROVER_EAGLE-LTSPICE_C0402
EPD_C5: 0.1uF/50V; ESP32_WROVER_EAGLE-LTSPICE_C0402
IC1: BD5229G-TR; SOT95P280X125-5N
IC4: XC6220A331MR-G; SOT95P280X120-5N
J1: FH34SRJ-24S-0.5SH_99_; FH34SRJ24S05SH99
J2: SAMACSYS_PARTS_USB4110-GF-A; SAMACSYS_PARTS_USB4110GFA
J3: QWIIC_RIGHT_ANGLE; JST04_1MM_RA
J4: 112A-TAAR-R03_ATTEND; 112ATAARR03ATTEND
L1: 744043680IND_4828-WE-TPC_WRE; IND_4828-WE-TPC_WRE
MCP73831: ESP32_WROVER_SPARKFUN-IC-POWER_MCP73831; ESP32_WROVER_SPARKFUN-IC-POWER_SOT23-5
PFMF.050.1: ESP32C6_VARISTORCN1812; ESP32C6_VARISTOR_CT/CN1812
Q1, Q2: 20V/4.2A/52mΩ/1.4W; ESP32_WROVER_SPARKFUN-DISCRETESEMI_SOT23-3
Q3: SI1308EDL-T1-GE3; SOT65P210X110-3N
R1, R1_PINH, R1_PINH1, R2_PINH, R2_PINH1, R4, R5, R6, R7, R9, R10: 10K; ESP32_WROVER_EAGLE-LTSPICE_R0402
R1_BAT: 200; ESP32_WROVER_EAGLE-LTSPICE_R0402
R1_PWRUSB: 100K; ESP32_WROVER_EAGLE-LTSPICE_R0402
R2: 2.2; ESP32_WROVER_EAGLE-LTSPICE_R0402
R2-USB, R2-USB1: 5k1; ESP32_WROVER_EAGLE-LTSPICE_R0402
R2_BAT: 2K; ESP32_WROVER_EAGLE-LTSPICE_R0402
R3: 0.47; ESP32_WROVER_EAGLE-LTSPICE_R0402
R8: 10k; ESP32_WROVER_EAGLE-LTSPICE_R0402
RESET_BUTTON: BUTTON_CUSYOMV1; MYBUTTON
R_BOOT: 10K; ESP32_WROVER_EAGLE-LTSPICE_R0402
R_CAPACITOR: 15; ESP32_WROVER_EAGLE-LTSPICE_R0402
R_CHANGE: 10K; ESP32_WROVER_EAGLE-LTSPICE_R0402
R_CL1: 10K; ESP32_WROVER_EAGLE-LTSPICE_R0402
R_RESET: 10K; ESP32_WROVER_EAGLE-LTSPICE_R0402
SENSOR2: ESP32_WROVER_BME680_BME6801; ESP32_WROVER_BME680_PSON80P300X300X100-8N
SJ1: SJ
TP1, TP2, TP3, TP4, TP5, TP6, TP7, TP8, TP9, TP10, TP11, TP12, TP13, TP14, TP15, TP16, TP17: TPTP20R; TP20R
U1: W25Q512JVEIQ; SON127P600X800X80-9N
U2: ESP32-C6-WROOM-1-N8; XCVR_ESP32-C6-WROOM-1-N8
U3: DS3231SN#; SOIC127P1032X265-16N
U4: MAX17048G+T10; SON50P200X200X80-9N

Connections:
3V3: C1_BAT2.1, C3.+, C9.1, D7.2 (ANODE), IC1.2 (VDD), IC4.5 (VOUT), J3.2, J4.P4 (VDD), Q2.3 (D), R1.2, R1_PINH1.2, R2_PINH1.2, R5.2, R6.2, R7.2, R8.2, R9.2, R10.2, R_BOOT.1, R_CHANGE.1, R_CL1.1, R_RESET.1, TP16.TP, U1.3 (!WP!(IO2)), U1.7 (!HOLD!/!RESET!(IO3)), U1.8 (VCC), U2.2 (3V3), U3.2 (VCC)
32KHZ: R2_PINH1.1, U2.9 (IO1), U3.1 (32KHZ)
DN: D1.1 (I/O1_1), J2.A7, J2.B7
DP: D1.3 (I/O2_1), J2.A6, J2.B6
EPD_3V3: C7.1, EPD_C5.2, J1.15, J1.16, L1.2, TP17.TP
EPD_3V3_C: Q2.1 (G), Q2.2 (S), R_CL1.2, TP13.TP, U2.18 (IO20)
EPD_BUSY: J1.9, TP9.TP, U2.26 (IO3)
EPD_CS: D6.2, J1.12, R9.1, TP10.TP, U2.11 (IO10)
EPD_DC: J1.11, TP11.TP, U2.5 (IO5)
EPD_RST: J1.10, TP12.TP, U2.21 (IO23)
FLASH_CS: D9.2, R5.1, U1.1 (!CS), U2.12 (IO11)
GDR: J1.2, Q3.1 (G), R4.2
GND: BOOT_BUTTON.1, BOOT_BUTTON.2, C1.2, C1_BAT.2, C1_BAT1.2, C1_BAT2.2, C2.2, C2_BAT.2, C3.-, C4_USB.2, C5.2, C5_USB.2, C6.2, C7.2, C8.2, C9.2, C10.2, C10_SUPERCAP.1, CHANGE_BUTTON.1, CHANGE_BUTTON.2, C_DELAY.2, D1.5 (VBUS), D3.1 (K), D6.1, D8.1, D9.1, D10.1, D11.1, D12.1, EPD_C1.1, EPD_C2.1, EPD_C5.1, EPD_C6.2, EPD_C7.2, EPD_C8.2, EPD_C9.2, EPD_C10.2, EPD_C11.2, EPD_C12.2, IC1.3 (GND), IC4.2 (VSS), J1.8, J1.17, J1.MP1, J1.MP2, J2.A1, J2.A12, J2.B1, J2.B12, J2.MP1, J2.MP2, J2.MP3, J2.MP4, J3.1, J4.G1 (GND_1), J4.G2 (GND_2), J4.G3 (GND_3), J4.G4 (GND_4), J4.P6 (VSS), MCP73831.2 (VSS), R1_PWRUSB.2, R2.1, R2-USB.2, R2-USB1.1, R2_BAT.1, R4.1, RESET_BUTTON.1, RESET_BUTTON.2, SENSOR2.2 (GND), SENSOR2.5 (SDO), SJ1.1, TP4.TP, TP5.TP, U1.4 (GND), U1.9 (EXP), U2.1 (GND), U2.28 (GND), U2.29_1 (GND), U2.29_2 (GND), U2.29_3 (GND), U2.29_4 (GND), U2.29_5 (GND), U2.29_6 (GND), U2.29_7 (GND), U2.29_8 (GND), U2.29_9 (GND), U3.13 (GND), U4.1 (CTG), U4.4 (GND), U4.6 (QSTRT), U4.9 (EP)
GPIO8: R1.1, U2.10 (IO8)
I2C_PW: C1.1, C2.1, R1_PINH.2, R2_PINH.2, SENSOR2.1 (CSB), SENSOR2.6 (VDD), SENSOR2.7 (VDDIO), U2.17 (IO19)
INT_RTC: R1_PINH1.1, TP15.TP, U2.8 (IO0), U3.3 (SQW/!INT)
IO/BOOT: BOOT_BUTTON.3, BOOT_BUTTON.4, C6.1, R_BOOT.2, U2.15 (IO9)
IO/CHANGE: C10.1, CHANGE_BUTTON.3, CHANGE_BUTTON.4, R_CHANGE.2, U2.23 (IO15)
MISO: D12.2, J4.P7 (DAT0), R8.1, TP6.TP, U1.2 (DO(IO1)), U2.27 (IO2)
MOSI: D11.2, J1.14, J4.P3 (CMD), R7.1, TP7.TP, U1.5 (DI(IO0)), U2.7 (IO7)
unnamed: J2.A5, R2-USB1.2
unnamed: J2.B5, R2-USB.1
unnamed: C1_BAT1.1, D2.1 (CATHODE), IC4.1 (VIN), IC4.3 (CE), Q1.2 (S)
unnamed: C4.1, D3.2 (A), D4.1 (K)
unnamed: MCP73831.5 (PROG), R2_BAT.2
unnamed: MCP73831.1 (STAT), R1_BAT.2
unnamed: CHG_LED.C, R1_BAT.1
unnamed: EPD_C6.1, J1.18
unnamed: D7.1 (CATHODE), R_CAPACITOR.2
unnamed: EPD_C1.2, J1.4
unnamed: EPD_C2.2, J1.5
unnamed: EPD_C7.1, J1.19
unnamed: EPD_C8.1, J1.20
unnamed: EPD_C10.1, J1.22
unnamed: EPD_C12.1, J1.24
unnamed: C_DELAY.1, IC1.5 (CT)
PREVGH: D5.2 (A), EPD_C9.1, J1.21
PREVGL: D4.2 (A), EPD_C11.1, J1.23
RESE: J1.3, Q3.2 (S), R3.2
RESE': R2.2, R3.1, SJ1.2
RESET: C5.1, IC1.1 (VOUT), RESET_BUTTON.3, RESET_BUTTON.4, R_RESET.2, U2.3 (EN)
RTC_RST: U2.16 (IO18), U3.4 (!RST)
RX: TP2.TP, U2.24 (RXD0/GPIO17)
SCK: D10.2, J1.13, J4.P5 (CLK), R6.1, TP8.TP, U1.6 (CLK), U2.6 (IO6)
SCL: J3.4, R2_PINH.1, SENSOR2.3 (SCK), U2.20 (IO22), U3.16 (SCL), U4.7 (SCL)
SDA: J3.3, R1_PINH.1, SENSOR2.4 (SDI), U2.19 (IO21), U3.15 (SDA), U4.8 (SDA)
SRC: C4.2, D5.1 (K), L1.1, Q3.3 (D)
SS_SD: D8.2, J4.P2 (CD/DAT3), R10.1, U2.4 (IO4)
TX: TP1.TP, U2.25 (TXD0/GPIO16)
USB_D+: D1.4 (I/O2_2), U2.14 (IO13)
USB_D-: D1.6 (I/O1_2), U2.13 (IO12)
VBAT: C2_BAT.1, MCP73831.3 (VBAT), Q1.3 (D), TP3.TP, U4.2 (CELL), U4.3 (VDD)
VBUS: C1_BAT.1, C4_USB.1, C5_USB.1, CHG_LED.A, D1.2 (GND), D2.2 (ANODE), MCP73831.4 (VIN), PFMF.050.1.2, Q1.1 (G), R1_PWRUSB.1, TP14.TP
VRTC: C8.1, C10_SUPERCAP.2, R_CAPACITOR.1, U3.14 (VBAT)
VUSB: J2.A4, J2.A9, J2.B4, J2.B9, PFMF.050.1.1

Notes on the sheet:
USB C connector & ESD protection
Display Type Selector
SD Card
LDO Voltage Regulator
E-Paper Drive Circuit
Li-Po Battery Charging Controller
ESP32 C6
Battery Charge Level
External NOR Flash 64MB
E-Paper Display Header
EPD Power
Environmental Sensor BME688
Voltage Supervisor + Reset & Boot / IO Button
RTC Module DS3231SN
Test Pads
Qwiic / Steamma QT
SPI ESD Protection Lines

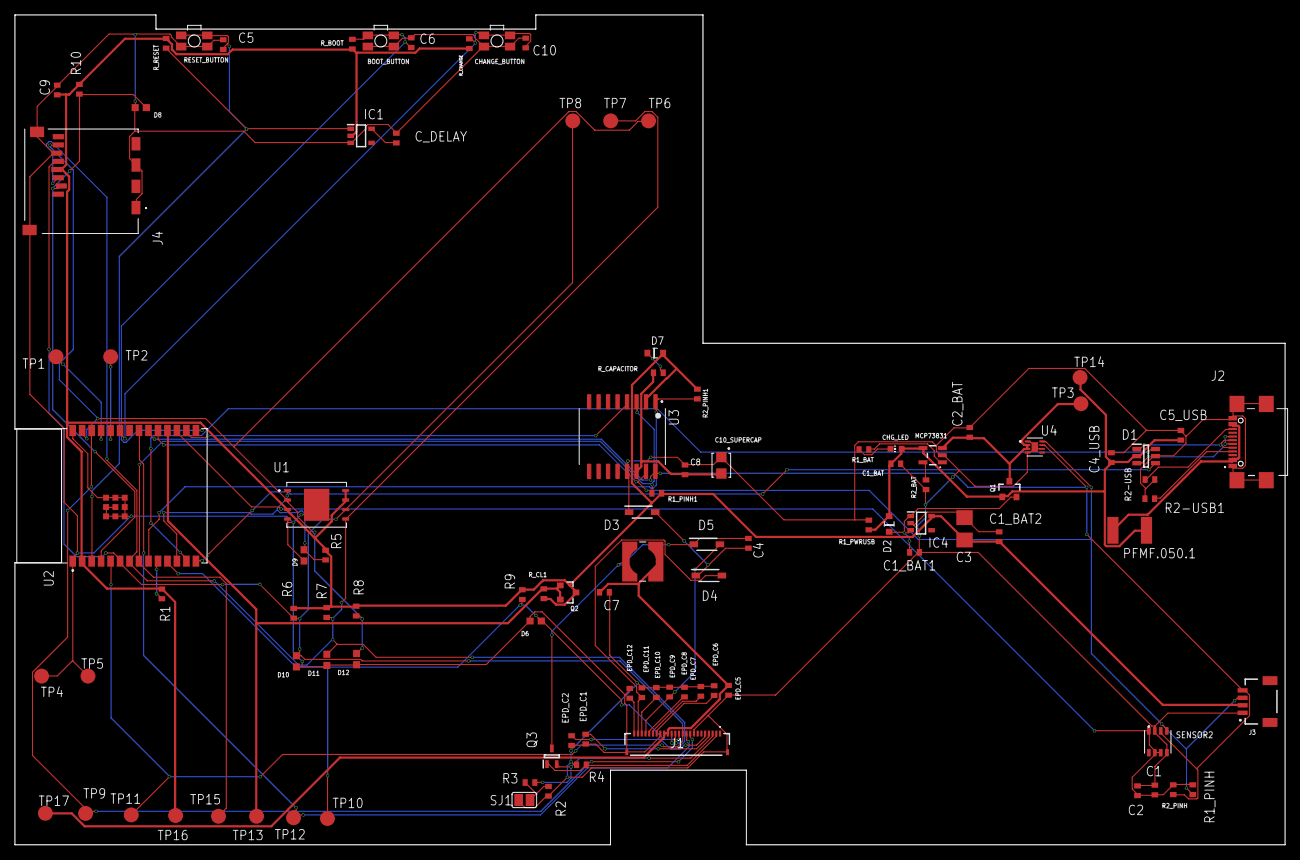
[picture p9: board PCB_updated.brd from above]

Board: 2 copper layers, 170.2 x 111.2 mm, 103 parts (0 on the bottom side), 55 nets.

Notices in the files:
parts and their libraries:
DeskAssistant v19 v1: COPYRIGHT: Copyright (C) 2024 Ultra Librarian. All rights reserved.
